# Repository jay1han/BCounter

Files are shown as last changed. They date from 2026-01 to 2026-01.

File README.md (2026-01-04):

# BCounter

Simple counter with SSD1306 display.

## Usage

### Buttons

- Button 1 wakes up, increments the counter and displays the count during 30 seconds

- Button 2, if pressed for 10 seconds while display is active, resets the counter

### Screen

Displays the count on 3 digits and a countdown bar to show remaining time until power off (30 seconds).

### Battery life

A LR44 1.5V battery should last several months and hundreds of button presses.
Test ongoing...

## Circuit

### MCU

The ESP32-C3
([datasheet](https://documentation.espressif.com/esp32-c3_datasheet_en.pdf))
is very much overpowered for this application, but it's the cheapest 32-bit MCU available
on [AliExpress](https://www.aliexpress.com/item/1005009495310442.html),
though RP2040-based modules are also around the same price.

### Power

A button battery (1.5V) feeds a boost converter 
([AliExpress](https://www.aliexpress.com/item/1005005553352585.html))
that outputs 3.3V,
which feeds directly into the ESP32-C3 module.

The module has a red LED to show power input.
This LED consumes about 1mA, so it's best to remove it.

### Display

The OLED display
([AliExpress](https://www.aliexpress.com/item/1005006408257788.html))
is connected to GPIO0 to GPIO3 as follows

| OLED pin | GPIO | Note |
|---|---|---|
| GND | 3 | 0V by software |
| VCC | 2 | 3.3V by software |
| SCL | 1 | |
| SDA | 0 | |

GPIO0 and GPIO1 are controlled by software. The MCU has enough output
to power the OLED module through the GPIO pins.

## Software

### Arduino IDE

Build was done using [Arduino IDE](https://docs.arduino.cc/software/ide/#ide-v2),
with the [Arduino ESP32](https://docs.espressif.com/projects/arduino-esp32/en/latest/installing.html) 
installed.

### Display

The datasheet for this particular display is available 
[here](https://www.icbanq.com/icdownload/data/ICBShop/Board/ZJY001_0.42_16P%20OLED.pdf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).
It's basically a SSD1306 driver, but care must be taken because
the starting column is at #28 (commands 0x0C and 0x11).

Font size is 8x16 with doubling,
so cell size 20x32 allows 3 digits on the 72x40 display with
8 vertical pixels and 12 horizontal pixels empty.
Bottom bar takes 60 pixels horizontally,
two pixels wide per second of timer.

The entire 60x40 active area is centered horizontally.

### Buttons

The reboot button is hard-wired to the reset pin.
The reset button is normally used for the strapping pin (GPIO9) to force
the MCU into download mode. When the MCU is already powered on, it can be read
on GPIO9 as a normal pull-up button.

### Deep sleep

The ESP32-C3's 
[deep sleep](https://docs.espressif.com/projects/esp-idf/en/stable/esp32/api-guides/low-power-mode/low-power-mode-soc.html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)
is used to "turn off".
We don't need a wake-up trigger, since the user is expected to press the reboot button.
Note that the display is also turned off when going to sleep.

### Persistent storage

ESP-IDF has a simple API for mounting and using a SPIFFS partition, see
[documentation](https://docs.espressif.com/projects/esp-idf/en/stable/esp32c3/api-reference/storage/spiffs.html).
We only use one file, containing the current count as text.
To avoid runaway counting, we reset the count to 1 when it reached 1000, which couldn't be displayed anyway.

## Box

A box has been designed to house the MCU module with the OLED module hard-soldered to it,
the boost converter and a LR44 button battery. The FreeCAD file is provided.

The two buttons end up deeply buried between the two modules,
so long columns help push them with a fingertip from outside the box.

The box must be put together using 4x M3x8 screws.

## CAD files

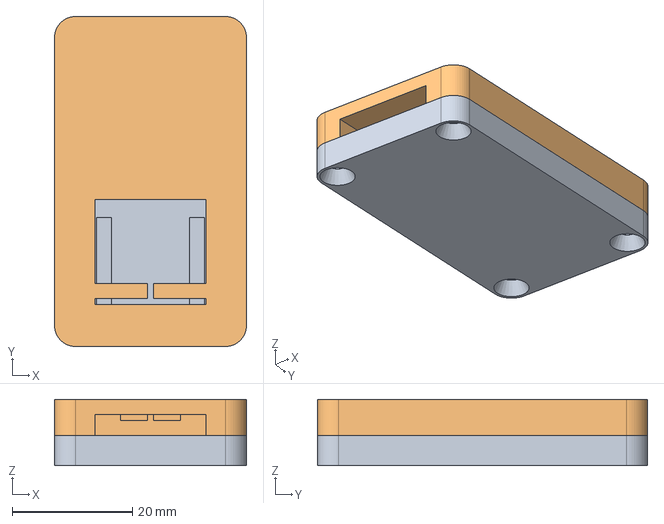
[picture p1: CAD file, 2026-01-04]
Counter.FCStd
32.0 x 55.0 x 11.0 mm
Base
Top

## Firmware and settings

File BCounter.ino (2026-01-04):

#include <Esp.h>
#include <Wire.h>
#include "esp_spiffs.h"

// ----------------------------
// I2C for OLED display SSD1306

#define I2C_ADDR     0x3C
#define I2C_GND      3
#define I2C_VCC      2
#define I2C_SCL      1
#define I2C_SDA      0

// Font: only digits

#define FONT_WIDTH 8
#define FONT_PITCH    (FONT_WIDTH + 2)

const unsigned char fontdata_top[][8] = {
    {0xFC,0xFE,0x87,0xC3,0xE3,0x77,0xFE,0xFC,},
    {0x00,0x0C,0x0E,0xFF,0xFF,0x00,0x00,0x00,},
    {0x0C,0x0E,0x07,0x83,0xC3,0xE7,0x7E,0x3C,},
    {0x06,0x07,0x03,0xC3,0xC3,0xE7,0xFE,0x3C,},
    {0xE0,0xF0,0xB8,0x9C,0x8E,0xFF,0xFF,0x80,},
    {0x3F,0x3F,0x33,0x33,0x33,0x73,0xE3,0xC3,},
    {0xF0,0xF8,0xDC,0xCE,0xC7,0xC3,0x83,0x00,},
    {0x03,0x03,0xC3,0xE3,0x73,0x3B,0x1F,0x0F,},
    {0x3C,0x3E,0xE7,0xC3,0xC3,0xE7,0x3E,0x3C,},
    {0x3C,0x7E,0xE7,0xC3,0xC3,0xE7,0xFE,0xFC,},
};

const uint8_t fontdata_bot[][8] = {
    {0x0F,0x1F,0x3B,0x31,0x30,0x38,0x1F,0x0F,},
    {0x00,0x30,0x30,0x3F,0x3F,0x30,0x30,0x00,},
    {0x3C,0x3E,0x37,0x33,0x31,0x30,0x30,0x30,},
    {0x18,0x38,0x30,0x30,0x30,0x39,0x1F,0x0F,},
    {0x01,0x01,0x01,0x01,0x01,0x3F,0x3F,0x01,},
    {0x0C,0x1C,0x38,0x30,0x30,0x38,0x1F,0x0F,},
    {0x0F,0x1F,0x39,0x30,0x30,0x39,0x1F,0x0F,},
    {0x00,0x00,0x3F,0x3F,0x00,0x00,0x00,0x00,},
    {0x0F,0x1F,0x39,0x30,0x30,0x39,0x1F,0x0F,},
    {0x00,0x30,0x30,0x38,0x1C,0x0E,0x07,0x03,},
};

#define LCD_H_RES     72
#define LCD_V_RES     40
#define LCD_PAGES     (LCD_V_RES / 8)
#define LINE_WIDTH    (LCD_H_RES / FONT_PITCH / 2)

// https://www.icbanq.com/icdownload/data/ICBShop/Board/ZJY001_0.42_16P%20OLED.pdf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

const unsigned char ssd1306_init[] = {
    0xAE | 0x00,          // SET_DISP            off
    0xD5, 0xF0,           // SET OSC DIV
    0xA8, LCD_V_RES - 1,  // SET_MUX_RATIO
    0xD3, 0x00,           // SET_DISP_OFFS
    0x40 | 0x00,          // SET_START_LINE
    0x8D, 0x14,           // SET_CHARGE_PUMP     0x10(ext) or 0x14(int)
    0x20, 0x02,           // SET_MEM_ADDRESS     page mode
    0xA0 | 0x01,          // SET_REG_REMAP       horizontal reverse start
    0xC0 | 0x08,          // SET_COM_OUT_DIR     horizontal reverse scan
    0xDA, 0x12,           // SET_COM_PIN_CFG     must be 0x02 if aspect ratio > 2:1, 0x12 otherwise
    0xAD, 0x30,           // SET_IREF           
    0x81, 0x1F,           // SET_CONTRAST
    0xD9, 0x22,           // SET_PRECHARGE
    0xDB, 0x20,           // SET_VCOM_DESEL
    0xA4,                 // SET_ENTIRE_ON
    0xA6 | 0x00,          // SET_NORM_INV (0x01 for inverse)
    0xAE | 0x01,          // SET_DISP            on
};

void ssd1306_cmd(unsigned char cmd) {
    Wire.beginTransmission(I2C_ADDR);
    Wire.write(0x80);
    Wire.write(cmd);
    Wire.endTransmission();
}

void displayOff() {
    digitalWrite(I2C_VCC, LOW);
    ssd1306_cmd(0xAE);
    ssd1306_cmd(0x00);
}

void sendPage(int page, unsigned char *buffer, int length) {
    ssd1306_cmd(0xB0 | page);
    ssd1306_cmd(0x0C);
    ssd1306_cmd(0x11);
        
    Wire.beginTransmission(I2C_ADDR);
    Wire.write(0x40);
    Wire.write(buffer, length);
    Wire.endTransmission();
}

unsigned char lines[4][LCD_H_RES];
unsigned char bar[LCD_H_RES];

void initDisplay() {
    pinMode(I2C_GND, OUTPUT);
    digitalWrite(I2C_GND, LOW);
    pinMode(I2C_VCC, OUTPUT);
    digitalWrite(I2C_VCC, LOW);
    delay(100);
    digitalWrite(I2C_VCC, HIGH);
    delay(100);
    
    memset(bar, 0, sizeof(bar));
    
    Wire.begin(I2C_SDA, I2C_SCL, 400000);
    Wire.beginTransmission(I2C_ADDR);
    if (Wire.endTransmission() == 0) {
        for (int i = 0; i < sizeof(ssd1306_init); i++) {
            ssd1306_cmd(ssd1306_init[i]);
        }
        delay(100);

        for (int page = 0; page < LCD_PAGES; page ++) {
            sendPage(page, bar, sizeof(bar));
        }
        Serial.println("I2C OLED initialized");
    } else {
        Serial.println("I2C OLED failed");
        esp_deep_sleep_start();
    }
}

byte nybble_low(byte original) {
    byte result = 0;
    for (int pos = 0; pos < 4; pos++) {
        if (original & (1 << pos)) result |= (3 << (pos * 2));
    }
    return result;
}

byte nybble_hi(byte original) {
    byte result = 0;
    for (int pos = 0; pos < 4; pos++) {
        if (original & (1 << (4 + pos))) result |= (3 << (pos * 2));
    }
    return result;
}

void displayNum(char *text) {
    int target = 8;

    for (int i = 0; i < strlen(text) && i < LINE_WIDTH; i++) {
        int index = text[i];
        if (index >= '0' && index <= '9') {
            index -= '0';
            for (int col = 0; col < FONT_WIDTH; col++) {
                lines[0][target] = nybble_low(fontdata_top[index][col]);
                lines[1][target] = nybble_hi(fontdata_top[index][col]);
                lines[2][target] = nybble_low(fontdata_bot[index][col]);
                lines[3][target] = nybble_hi(fontdata_bot[index][col]);
                target++;
                lines[0][target] = nybble_low(fontdata_top[index][col]);
                lines[1][target] = nybble_hi(fontdata_top[index][col]);
                lines[2][target] = nybble_low(fontdata_bot[index][col]);
                lines[3][target] = nybble_hi(fontdata_bot[index][col]);
                target++;
            }
        } else {
            for (int col2 = 0; col2 < FONT_WIDTH * 2; col2++) {
                lines[0][target] = lines[1][target] = lines[2][target] = lines[3][target] = 0x00;
                target++;
            }
        }
        
        for (int space = 0; space < 4; space++) {
            lines[0][target] = lines[1][target] = lines[2][target] = lines[3][target] = 0x00;
            target++;
        }
    }

    for (; target < LCD_H_RES; target++) {
        lines[0][target] = lines[1][target] = lines[2][target] = lines[3][target] = 0x00;
    }
    
    for (int sub = 0; sub < 4; sub++) {
        sendPage(sub, lines[sub], LCD_H_RES);
    }
}

void displayBar(int seconds) {
    if (seconds >= 30) seconds = 30;
    
    int col = 0;
    if (seconds >= 0) {
        for (; col <= seconds; col++) {
            bar[66 - col * 2] = 0x0F;
            bar[67 - col * 2] = 0x0F;
        }
    } 
    for (; col <= 30; col++) {
        bar[66 - col * 2] = 0;
        bar[67 - col * 2] = 0;
    }
    sendPage(4, bar, LCD_H_RES);
}

//-----------------------------
// Storage

esp_vfs_spiffs_conf_t esp_vfs_spiffs_conf = {
    .base_path = "/fs",
    .partition_label = NULL,
    .max_files = 1,
    .format_if_mount_failed = true
};

void initFs() {
    esp_err_t err = esp_vfs_spiffs_register(&esp_vfs_spiffs_conf);
    if (err != ESP_OK) {
        Serial.printf("SPIFFS register => %d\n", err);
        esp_spiffs_format(NULL);
        esp_deep_sleep_start();
    }
}

int readCount() {
    int count = 0;
    FILE *f = fopen("/fs/count", "r");
    if (f == NULL) {
        Serial.println("Error opening file for read");
    } else {
        fscanf(f, "%d", &count);
        fclose(f);
    }
    return count;
}

void setCount(int count) {
    FILE *f = fopen("/fs/count", "w");
    if (f == NULL) {
        Serial.println("Error opening file for write");
    } else {
        fprintf(f, "%d", count);
        fclose(f);
    }
}

// Button

#define PIN_BUTTON   9

bool buttonDown() {
    return digitalRead(PIN_BUTTON) == LOW;
}

void setup() {
    Serial.begin(115200);
    pinMode(PIN_BUTTON, INPUT);
    initDisplay();
    displayNum("000");
    initFs();
    
    int count = readCount();
    if (count < 999) count++;
    if (count > 999) count = 1;
    setCount(count);

    char num[4];
    sprintf(num, "%3d", count);
    displayNum(num);
    displayBar(60);
}

void loop() {
    static int lastUpdate = 0;
    int seconds = millis() / 1000;
    if (seconds > 30) {
        if (buttonDown()) {
            setCount(0);
            ESP.restart();
        }
        displayOff();
        esp_deep_sleep_start();
        return;
    }
    if (seconds != lastUpdate) displayBar(30 - seconds);
    
    static bool button = false;
    static int pressed = 0;
    
    if (buttonDown()) {
        if (!button) {
            Serial.printf("Button down at %ds\n", seconds);
            button = true;
            pressed = seconds;
        } else {
            if (seconds - pressed > 10) {
                setCount(0);
                ESP.restart();
            }
        }
    } else {
        if (button) {
            Serial.println("Button up");
            button = false;
        }
    }
}
